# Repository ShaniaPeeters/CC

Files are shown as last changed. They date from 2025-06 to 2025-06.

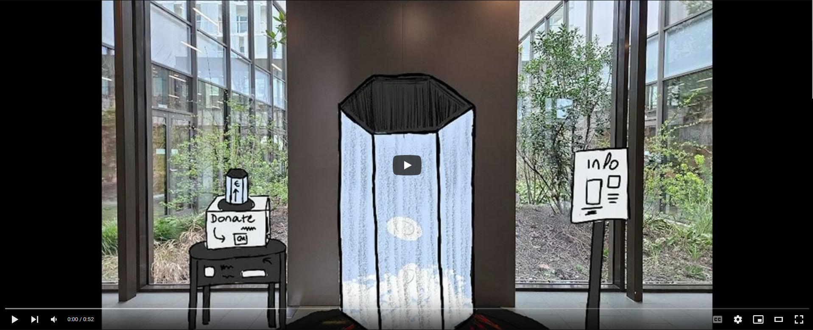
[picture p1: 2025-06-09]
assets/Screenshot 2025-06-09 100021.png

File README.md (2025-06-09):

# Inhoud:
- Video
- Stap voor stap
- Code
- Valkuilen

## Video
Bekijk de video (https://www.youtube.com/watch?v=g39wajMhOLU)

## Stap voor stap
### Benodigdheden:
- 3 programeerbare LED strips van 150 LEDS (en stroomvoorziening)
- 3 Houten panelen van 38 op 118
- 10 houten panelen van 38 op 38
- 3 plexiglas platen van 38 op 118
- 18 enkele connectors
- 6 dubbele connectors
- raspberry pi 4 (met gpio expansion)
- soldeerbout
- boormachine
- een USB microfoon
- veel bouten van 6mm op 20 ( en bijpassende moeren)
- kabeltjes voor de LEDS
- Een licht doorlatende zwarte doek van minstens 1.5m op 3m
- keramieke borden
- Een 3D printer
- lijm
- Laptop met visual studio code
- Ethernet kabel
- lasercutter of een zaag
- Zwarte acrylverf

### De doos:
Lasercut of zaag de panelen op de gewenste grote. Bij Lasercutten voorzij best de gaatjes voor de connectors al op voorhand, deze zijn 6mm in diameter. De gaatjes kan je echter later ook nog boren. 
Op een van de kleine houte panelen voorzie je gaatjes om het geluid van de vallende borden door te laten naar de microfoon. Verf alle houten panelen zwart.
### De LEDS:
Van de 3 LED strips maken we 6 door deze doormidden te knippen. Zorg ervoor dat bijde kanten 74 LEDS hebben.
Soldeer dan elks 2 LED strips aan elkaar (doolmiddel van kabbeltjes) met voldoende spatie ertussen zodat we later deze over de grond kunnen versprijden.
### De connectors:
Gebruik een 3D printer om de connectors af te printen. Gebruik hiervoor PLA of PetG. Best in een zwart fillament, anders kan je ze ook gewoon zwart schilderen.
### De Raspberry Pi:
Zorg ervoor dat je visual studio code op de raspberry pi instaleert zodat je via ssh de code op de raspberry kan zetten. Instaleer dan al de benodigde libraries voor de code. 
### Alles samen:
Sluit de microfoon en de LEDS aan op de raspberry pi. Gebruik de connectors om de houten en plexiglas panelen aan elkaar te bevestigen. 6 van de kleine panelen komen vanonder, de 6 grote vanboven. De 4 overblijvende panelen lijm je aan elkaar om een cubus vormige doos te maken zonder voor of onderkant, hier steken we de microfoon en raspberry pi onder. Bevestig de LEDS op de gewenste locatie op de vloer. Leg een stuk hout of iets dergerlijk onder waar de doos komt te staan. Bedek deze dan met de zwarte doek. Plaats dan de doos op zijn plaats. Steek alles in het stopcontact en gebruik het commando in de code om het programma op te runnen in de terminal.
## Code
Deze code ( main.py ) is bedoeld om een NeoPixel LED-strip aan te sturen op basis van het geluidsniveau dat wordt gemeten via een microfoon. Het script werkt als volgt:

1. **Audio-invoer**  
   De code gebruikt de pyaudio-bibliotheek om continu audio op te nemen via de microfoon. Het geluidsniveau wordt berekend met behulp van RMS (Root Mean Square) en piekwaarde.

2. **Berekenen van het aantal actieve LEDs**  
   Op basis van het gemeten geluidsniveau wordt bepaald hoeveel LEDs moeten oplichten. Hoe harder het geluid, hoe meer LEDs er aan gaan.

3. **Kleuren en animatie**  
   De LEDs worden verdeeld in drie kleurzones (rood, oranje, geel) afhankelijk van hun positie en het aantal actieve LEDs. Bij verandering van het geluidsniveau wordt een vloeiende overgang (fade) tussen het oude en nieuwe aantal actieve LEDs weergegeven.

4. **Aansturen van meerdere strips**  
   De code ondersteunt drie LED-strips die allemaal hetzelfde patroon tonen.

5. **Uitschakelen**  
   Bij het stoppen van het script (Ctrl+C) worden alle LEDs netjes uitgezet.

## Valkuilen
**Let op:**
- Het script moet met rootrechten worden uitgevoerd vanwege toegang tot de hardware (sudo ...).
- De gebruikte pinnen en het aantal LEDs moeten overeenkomen met je hardware-opstelling.

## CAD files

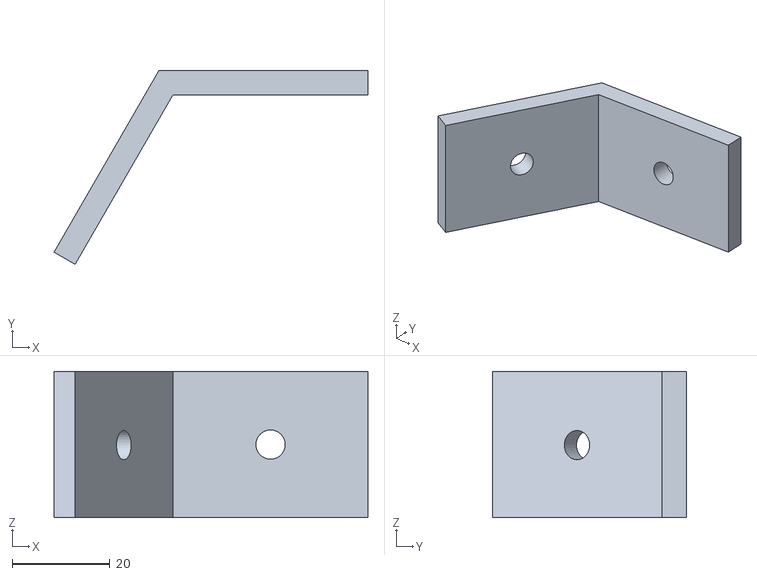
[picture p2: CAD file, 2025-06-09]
assets/testConnector.stl
64.4 x 39.7 x 30.0

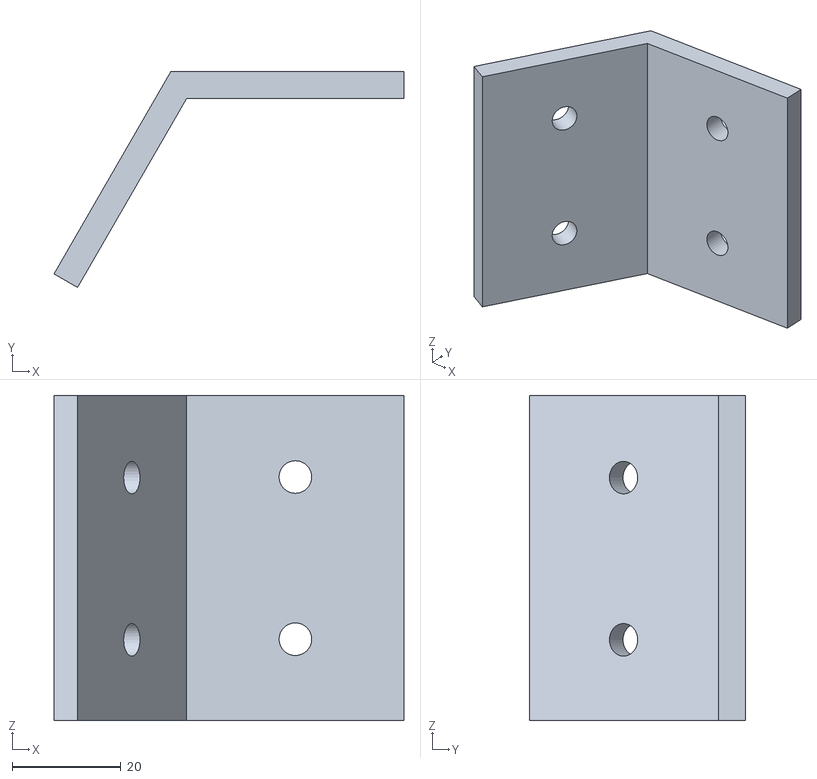
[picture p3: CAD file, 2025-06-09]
assets/testConnector2.stl
64.4 x 39.7 x 59.8

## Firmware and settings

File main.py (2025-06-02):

import pyaudio
import numpy as np
import time
import board
import neopixel
import collections

#To use input "sudo $(which python) /home/piremote/Desktop/CC/main.py" into terminal 

# LED strip configuration for NeoPixel
TOTAL_LEDS = 148
SEGMENT_SIZE = 74  # 74 LEDs per segment

# LED pins for the three strips
LED_PINS = [board.D18, board.D12, board.D21]

# Initialize the NeoPixel strips in a list
led_strips = [neopixel.NeoPixel(pin, TOTAL_LEDS, brightness=0.2, auto_write=False, pixel_order=neopixel.GRB)
              for pin in LED_PINS]

prev_active = 0

def get_color_relative(i, active_count):
    if active_count == 0:
        return (0, 0, 0)
    cutoff = active_count / 3
    if i < cutoff:
        return (255, 0, 0)        # red
    elif i < 2 * cutoff:
        return (255, 75, 0)      # orange
    else:
        return (255, 225, 0)      # yellow

def build_led_colors(active_count):
    # Build colors for one 74-LED segment
    colors = []
    for i in range(SEGMENT_SIZE):
        if i < active_count:
            colors.append(get_color_relative(i, active_count))
        else:
            colors.append((0, 0, 0))
    # Second segment is the reverse of the first
    return colors + list(reversed(colors))

def update_leds_immediate(active_count):
    # Update all LED strips with the same colors
    full_colors = build_led_colors(active_count)
    for strip in led_strips:
        strip[:] = full_colors
        strip.show()
    print("Active LEDs per segment:", active_count)

def update_leds_animated(new_active):
    global prev_active
    if new_active != prev_active:
        old_colors = build_led_colors(prev_active)
        new_colors = build_led_colors(new_active)

        delta = abs(new_active - prev_active)
        # If fading out, use fixed number of steps and longer delay for a slower fade-out.
        if new_active < prev_active:
            steps = 20         # Fade-out slower, independent of delta
            step_delay = 0.05  # Longer delay for fade-out
        else:
            min_steps = 10
            steps = max(min_steps, delta + 1)
            step_delay = 0.015

        for step in range(steps):
            # Use cosine easing for a smooth fade
            t = (1 - np.cos(np.pi * step / (steps - 1))) / 2 if steps > 1 else 1
            blended_colors = []
            for old, new in zip(old_colors, new_colors):
                blended_colors.append((
                    int(old[0] * (1 - t) + new[0] * t),
                    int(old[1] * (1 - t) + new[1] * t),
                    int(old[2] * (1 - t) + new[2] * t)
                ))
            for strip in led_strips:
                strip[:] = blended_colors
                strip.show()
            time.sleep(step_delay)

        prev_active = new_active
        print("Active LEDs per segment:", new_active)

def turn_off_leds():
    for strip in led_strips:
        for i in range(SEGMENT_SIZE):
            strip[i] = (0, 0, 0)
            idx = TOTAL_LEDS - 1 - i
            strip[idx] = (0, 0, 0)
        strip.show()

# Audio stream configuration
CHUNK = 1024
FORMAT = pyaudio.paInt16
CHANNELS = 1
RATE = 44100

p = pyaudio.PyAudio()
stream = p.open(format=FORMAT,
                channels=CHANNELS,
                rate=RATE,
                input=True,
                frames_per_buffer=CHUNK)

print("Monitoring audio... Press Ctrl+C to stop.")

MIN_RMS_THRESHOLD = 1000.0  # Only react to sounds louder than this value

# Define a maximum effective value (adjust based on your environment)
MAX_EFFECTIVE = 3000.0

# Parameters for our basic onset detection
HISTORY_SIZE = 10  # number of recent effective values to average
THRESHOLD_MULTIPLIER = 1.5  # how many times above the average to trigger
EXTRA_MINIMUM = 20.0  # additional absolute boost to avoid false triggers

energy_history = collections.deque(maxlen=HISTORY_SIZE)
gain = 3.0  # Amplification factor

try:
    while True:
        data = stream.read(CHUNK, exception_on_overflow=False)
        samples = np.frombuffer(data, dtype=np.int16).astype(np.float32)
        rms = np.sqrt(np.mean(np.square(samples)))
        peak = np.max(np.abs(samples))
        
        # Combine RMS and peak to capture transients
        effective = max(rms, peak / 1000.0)
        effective *= gain
        if np.isnan(effective):
            effective = 0.0

        # Update moving average (optional, if you still want to monitor trends)
        energy_history.append(effective)
        moving_avg = np.mean(energy_history) if energy_history else 0.0

        # Map the effective value to a number of active LEDs
        if effective < MIN_RMS_THRESHOLD:
            active_count = 0
        elif effective > MAX_EFFECTIVE:
            active_count = SEGMENT_SIZE
        else:
            active_count = int(((effective - MIN_RMS_THRESHOLD) / (MAX_EFFECTIVE - MIN_RMS_THRESHOLD)) * SEGMENT_SIZE)
        
        update_leds_animated(active_count)
        
        time.sleep(0.05)
except KeyboardInterrupt:
    pass

stream.stop_stream()
stream.close()
p.terminate()

turn_off_leds()
print("Stopped audio monitoring")

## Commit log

2025-03-18 Add audio input handling and LED control for sound detection
2025-03-24 Comment out LED library import for testing on non-Raspberry Pi
2025-04-24 led colour test
2025-04-24 Dynamically count LEDs and adjust volume thresholds for triggering
2025-04-24 Refactor LED handling to support multiple LED strips and improve audio-triggered LED updates
2025-05-12 Refactor LED update logic to improve efficiency and adjust volume thresholds for triggering
2025-05-12 Update LED color definitions and refine volume threshold logic for triggering
2025-05-19 Update LED configurations to support multiple strips and adjust minimum volume threshold
2025-05-19 Refactor LEDStrip initialization to support multiple strips and adjust parameters for LED configurations
2025-05-20 simple LED output based on audio input, 1 ledstrip 2 segments
2025-05-20 Enhance LED animation and audio response: implement smoother transitions using cosine easing and combine RMS with peak values for better transient detection.
2025-05-20 Enhance LED animation: implement smoother transitions with cosine easing and adjust audio response thresholds for better transient detection.
2025-06-09 added thumbnail and 3D printer files
    [testConnector.stl, testConnector2.stl]
